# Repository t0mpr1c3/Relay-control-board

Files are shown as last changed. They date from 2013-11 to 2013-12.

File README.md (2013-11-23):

Relay-control-board
===================

Control board for NAIS JSM1A or Songle SRD NO relays on Dangerous Prototypes DP5031 standard PCB size.

Derived from Sparkfun Electronics COM-11041 designed by N. Seidle and Joel Bartlett.

The component values are designed for VCC = 5 VDC. For VCC = 12 VDC, use R2 = 2.2K and R4 = 3.3K.

Released under Creative Commons Attribution Share-Alike 3.0 License. http://creativecommons.org/licenses/by-sa/3.0

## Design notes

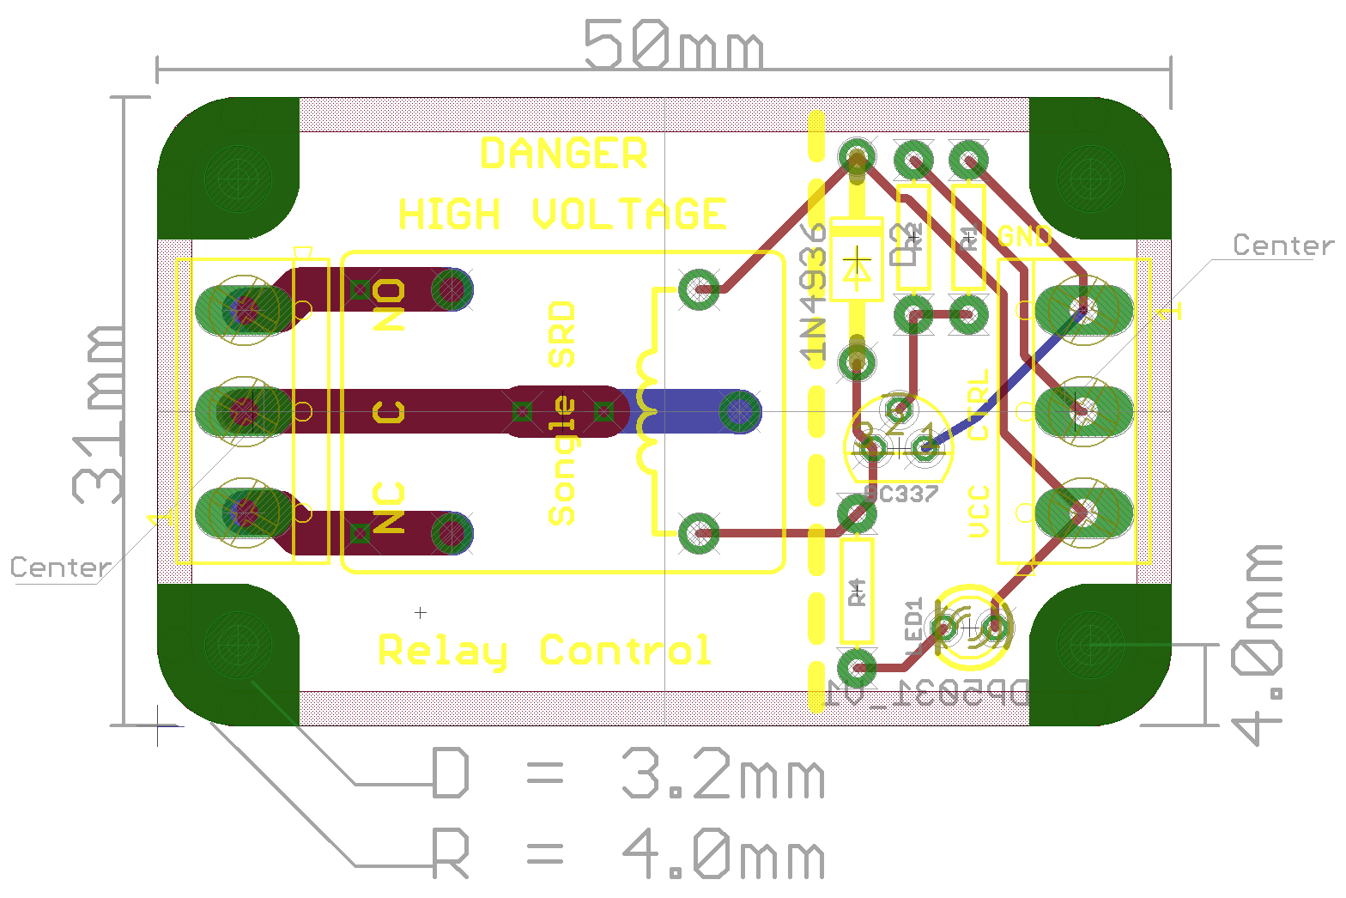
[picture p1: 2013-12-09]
hardware/RB01/RB01-brd.png

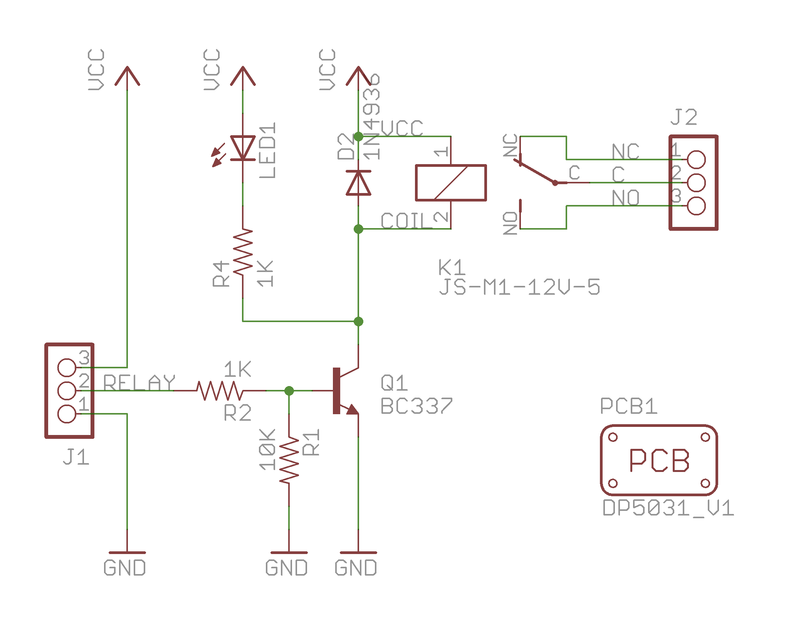
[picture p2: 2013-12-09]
hardware/RB01/RB01-sch.png

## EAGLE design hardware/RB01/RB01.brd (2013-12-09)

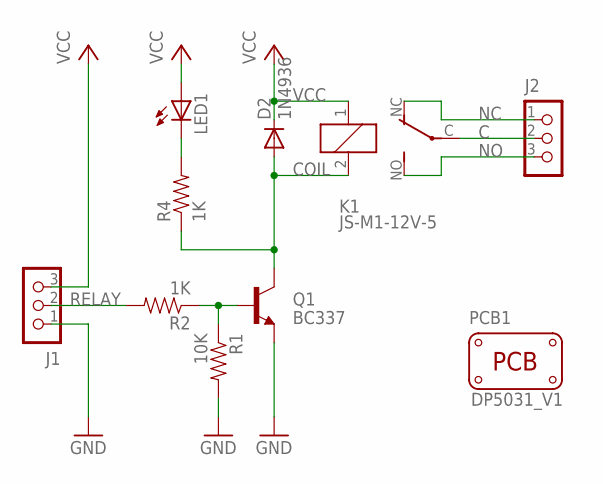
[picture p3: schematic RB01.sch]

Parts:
D2: 1N4936; DO41-10
J1, J2: CON_TERMINAL_BLOCK_03-5MM; TERMINAL_BLOCK_3P_5
K1: JS-M1-12V-5; JS-M; MPN JSM1-12V-5
LED1: LED-3MM
PCB1: PCB_DP_RECTANGLE-31X50; DP5031_V1
Q1: BC337; TO92
R1: 10K; AXIAL-0.3
R2, R4: 1K; AXIAL-0.3

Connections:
C: J2.2, K1.C
COIL: D2.A, K1.2, Q1.3 (C), R4.P$1 (1)
GND: J1.1, Q1.1 (E), R1.P$2 (2)
unnamed: Q1.2 (B), R1.P$1 (1), R2.P$1 (1)
unnamed: LED1.K (C), R4.P$2 (2)
NC: J2.1, K1.NC (O)
NO: J2.3, K1.NO (S)
RELAY: J1.2, R2.P$2 (2)
VCC: D2.C, J1.3, K1.1, LED1.A

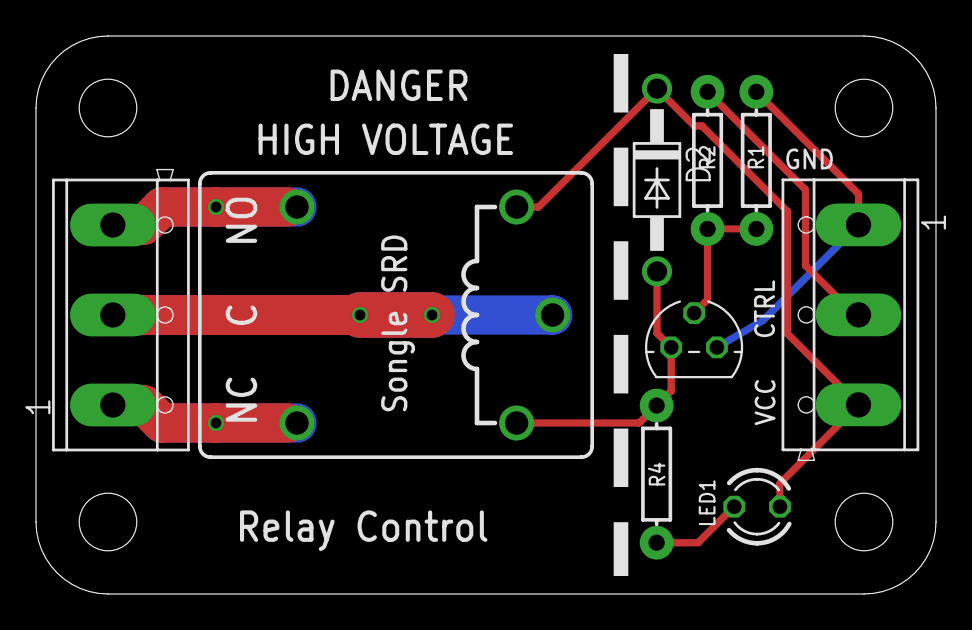
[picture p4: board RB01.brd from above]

Board: 4 copper layers, 50.0 x 31.0 mm, 11 parts (1 on the bottom side), 9 nets.

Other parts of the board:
U$2: OSHW-LOGO-S

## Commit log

2013-11-23 RB01 first draft
    [RB01.brd, RB01.sch]
2013-11-23 BC337s instead of BC546s
    [RB01.brd, RB01.sch]
2013-11-24 Magic Smoke logo
    [RB01.brd, RB01.sch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]
2013-11-25 tweak gerbers
    [RB01.brd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]
2013-11-26 JS-M1 relay package
    [RB01.brd, RB01.sch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]
2013-11-27 reorganize folders
    [RB01.GBL, RB01.GBO, RB01.GBP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]
2013-12-03 2mm clearance
    [RB01.brd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]
2013-12-04 hot traces on bottom only
    [RB01.brd, RB01.sch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]
2013-12-09 faster higher-power diode closer to coil
    [RB01.brd, RB01.sch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]

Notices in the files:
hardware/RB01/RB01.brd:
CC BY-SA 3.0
